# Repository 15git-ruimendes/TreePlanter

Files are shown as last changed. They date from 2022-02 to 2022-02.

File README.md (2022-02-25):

# TreePlanter (RePlantProject)

This project was developed under the guidance and tutelage of professor Armando Sousa and engineer Rui Coutinho has a semester project applied in the curricular unit of engineering systems at the faculty of engeneering at univerisity of Porto.

The final objective of this project is the creation of a smart autonomous planting machine capable of planting a differently sized seedlings amongs harsh and changable terrain.

The scope of the devolpment portion achived throught this semester resulted in the following prototype.

## Directory Organization 

The code gathered in this directory was organized as follows:

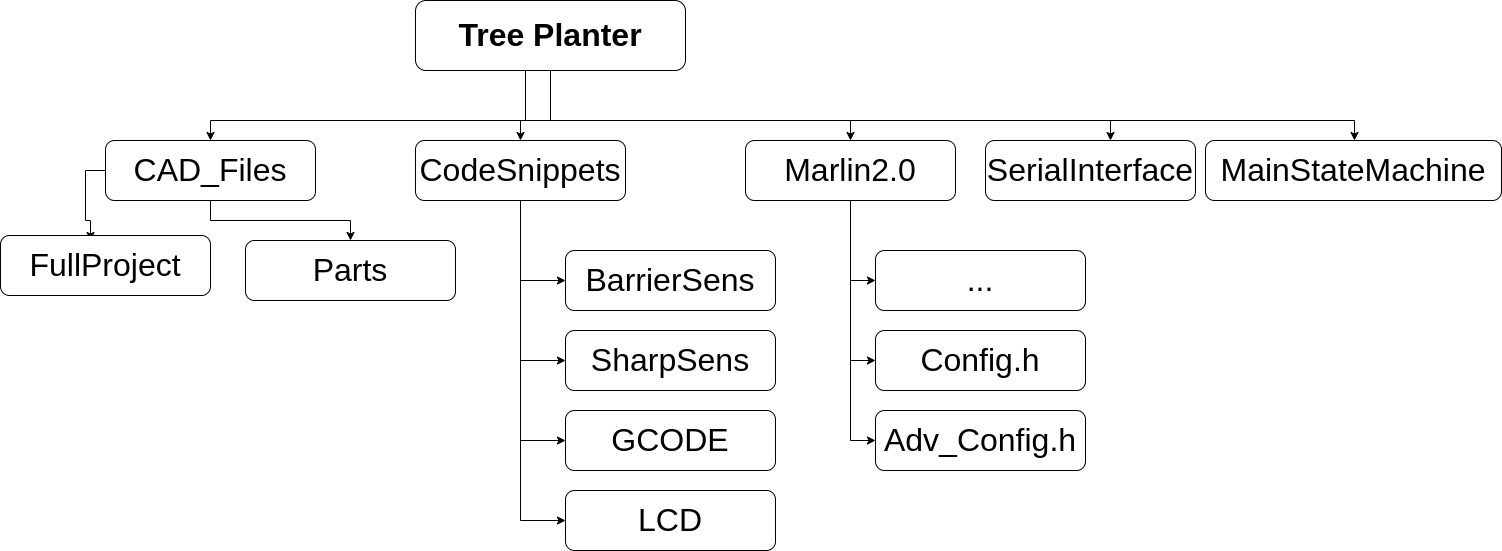
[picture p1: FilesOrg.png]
Files Diagram
  
  
  Thusly, the code present in the Marlin folder discribes the firmware used to control the manipulator that moves the drill. This firmware was corrected and altered for the porpouses of this project and to control and combine with the shield RAMPS 1.4 used.
  
  Next the code sections presented in MainStateMachine gather the hardware test code for the different sensores used and a liberarly for the LCD display. This folder also includes the main code used to control this project.
  The folder named SerialInterface presents the code used to create the serial interface, this code was developed using PySide2 and QtCreator.
  
  ## Connections Diagram
  
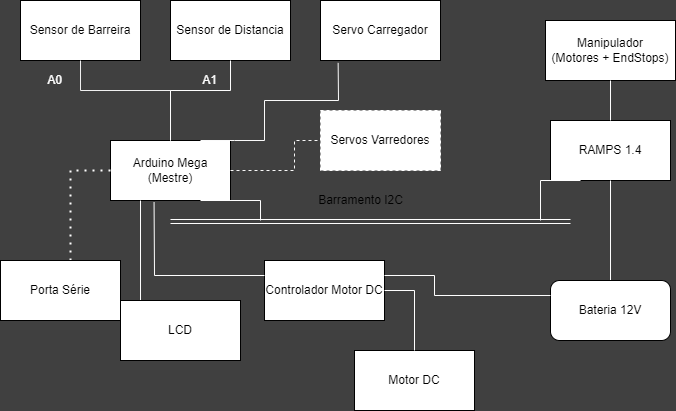
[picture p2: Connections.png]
Connection Diagram
  
  
  ## State Machine Diagram
  
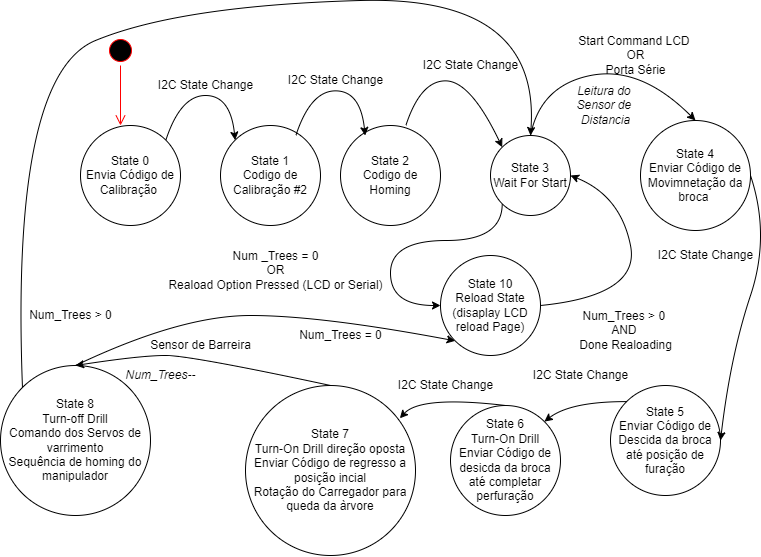
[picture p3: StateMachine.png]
State Machine Diagram


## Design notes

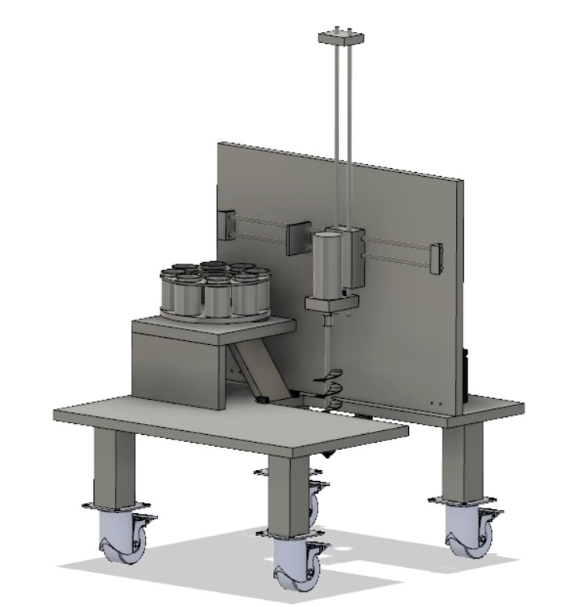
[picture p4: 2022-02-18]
GUI_TreePlanter/Pos2.jpg

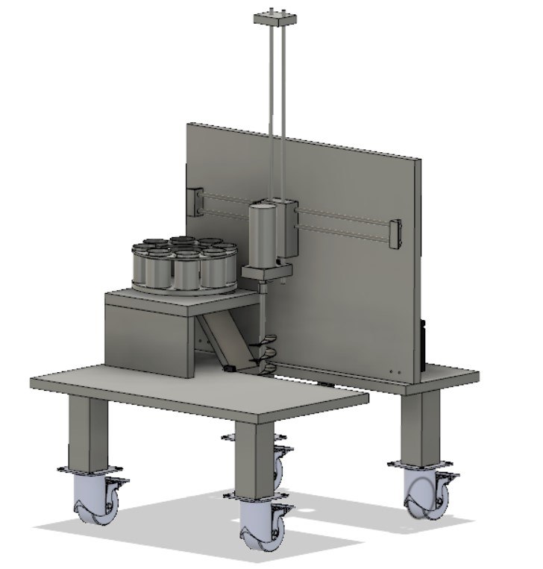
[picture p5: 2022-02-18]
GUI_TreePlanter/Pos1.jpg

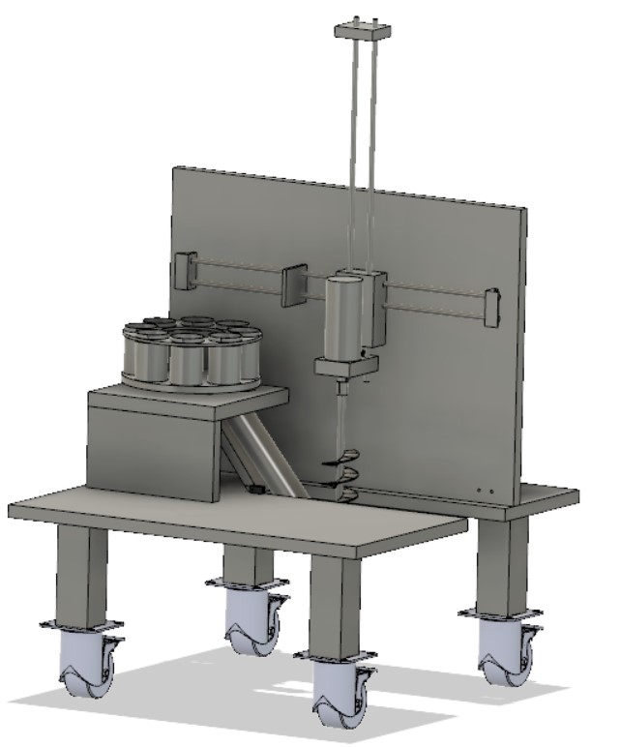
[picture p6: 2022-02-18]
GUI_TreePlanter/Pos4.jpg

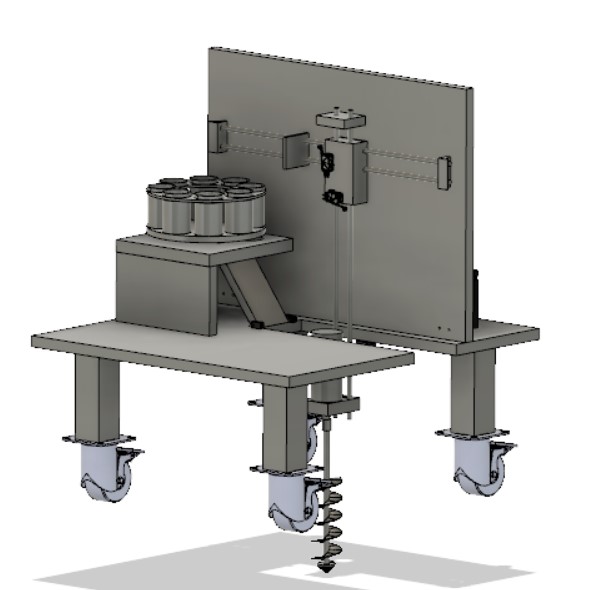
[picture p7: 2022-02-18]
GUI_TreePlanter/Pos3.jpg

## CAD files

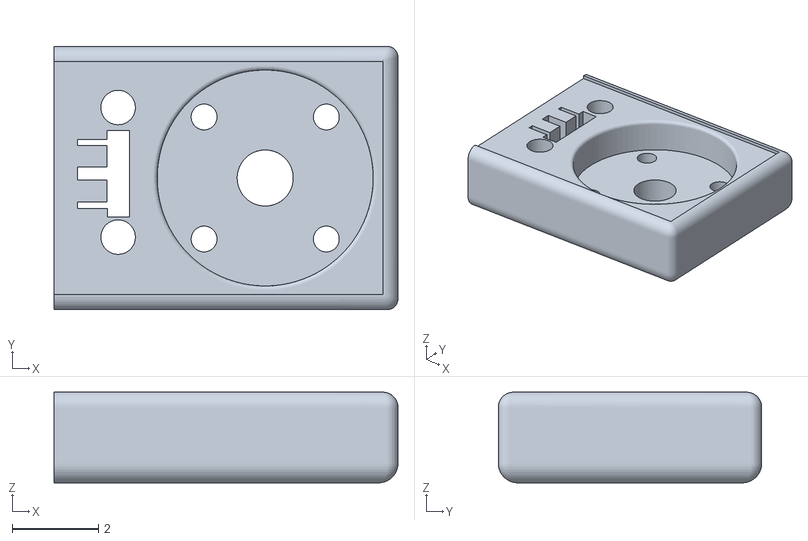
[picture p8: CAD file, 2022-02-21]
CAD_Files/IndividualParts/DC_Mount.stl
7.97 x 6.10 x 2.10

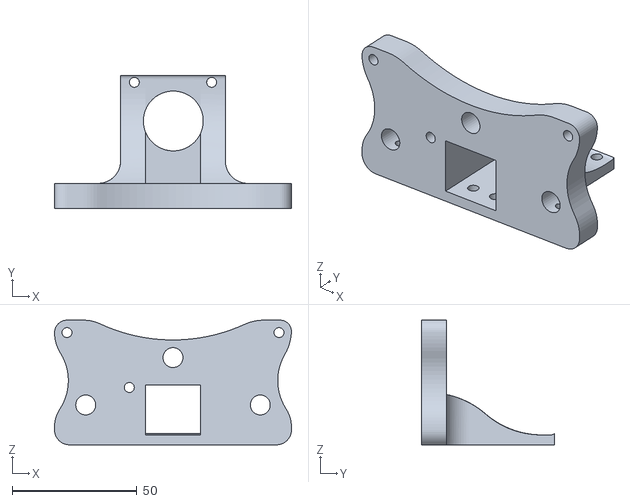
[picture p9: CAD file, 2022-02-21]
CAD_Files/IndividualParts/ManipulatorMountSimpler.stl
95.0 x 53.2 x 50.0

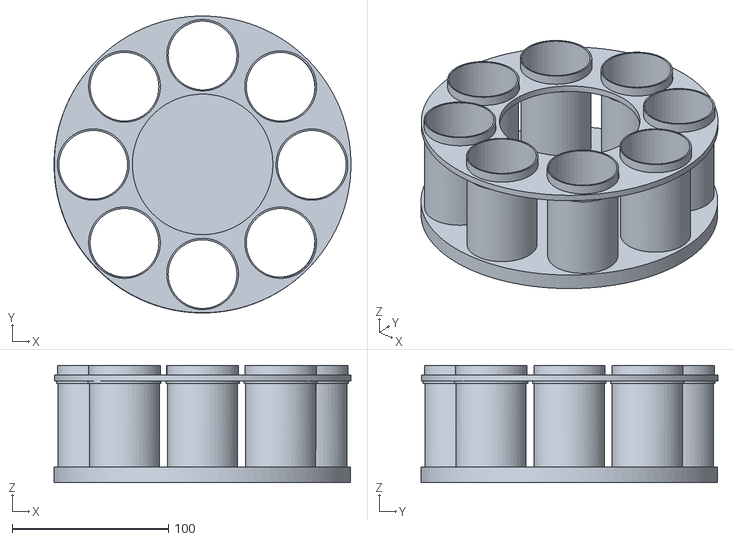
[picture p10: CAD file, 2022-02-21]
CAD_Files/IndividualParts/Carregador.stl
190.1 x 190.2 x 75.0

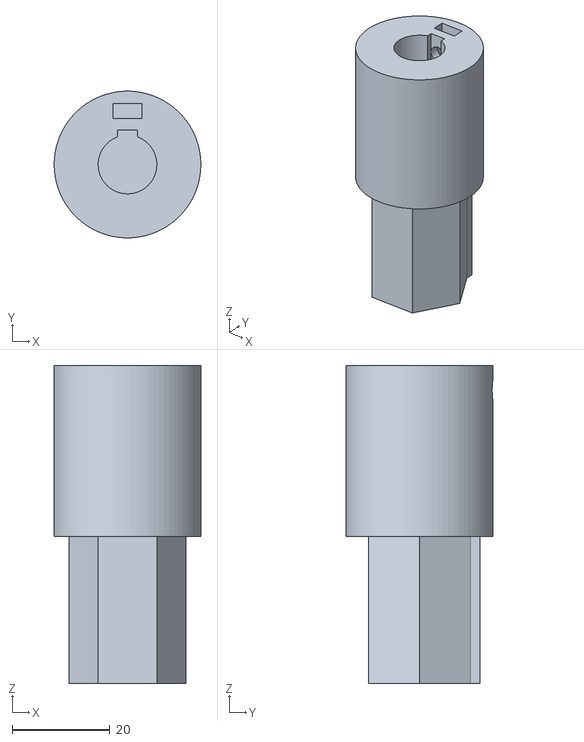
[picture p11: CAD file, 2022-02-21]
CAD_Files/IndividualParts/Coupler.stl
30.0 x 30.0 x 65.0

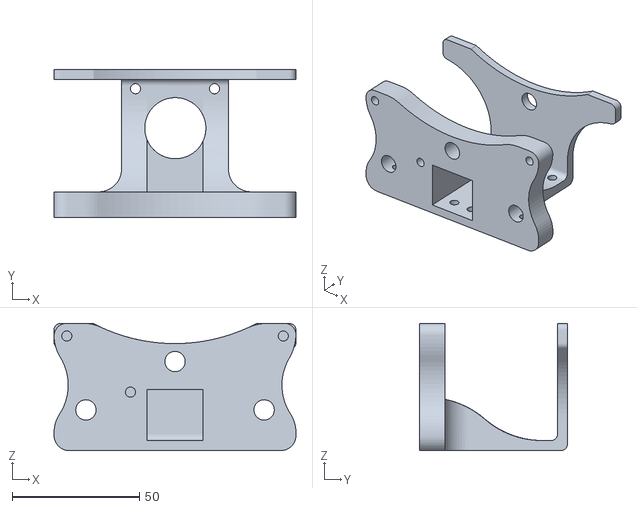
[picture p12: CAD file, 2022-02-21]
CAD_Files/IndividualParts/ManipulatorMount.stl
95.0 x 58.0 x 50.0

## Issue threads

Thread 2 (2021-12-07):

I2C communication Slave-Master

AlexMiranda16, 2021-12-07:
Slave can send data to the master

AlexMiranda16, 2021-12-08:
Since the master is the one that request a response from the slave, the slave says if it's free or not.
A weird bug makes some times the slave locked in a G-code command. Might be a g-code/Marlin problem.
A fix is to make the slave a "master" and he will send when it's ready to receive a new command, instead of being asked if it's free or not

AlexMiranda16, 2021-12-18:
I2C communication doesn't seems to be the problem.
The problem might be in the queue.advance that does not "lock" the ramps code, asking right away for a new command to the Arduino.
The queue is full and does not accept more commands, due to a very long time of command execution.
A solution might be using M400 command for ensure that all the moves are finished.

Closed 2021-12-31.

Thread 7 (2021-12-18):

Adjust micro-stepping in Gcode and Ramps

AlexMiranda16, 2021-12-18:
Configuration required to adjust the manipulator (and other subsystem modules eventually)

AlexMiranda16, 2021-12-18:
Steps required to configure the Steps/MM motor movement in Ramps (X, Y, Z):

- In "configuration.h" adjust the step_per_unit values;
- Use a ruler (or other precise way of measure) to measure the current place of the "head"
- Make it move X mm (like 100mm)
- Measure the new location to see how much it really moves
- Make the calculation: (steps_per_unit * Xmm) / actualmovement
- Replace the step_per_unit with the new value
- Repeat previous steps again until obtained reasonable results and to other axis

AlexMiranda16, 2021-12-19:
In this link it has some more formulas:
https://www.matterhackers.com/news/3d-printer-firmware-settings-stepper-motor-configuration
There is another way to calibrate belt driven axis (our case X and Y) but it looks more complicated.

AlexMiranda16, 2022-01-07:
Configured!
There is no micro-stepping applied.
Steps per unit are 5.15 in the manipulator (a variation of about 1mm in every 100mm)

Closed 2022-01-07.

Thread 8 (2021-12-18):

Configure endstops

AlexMiranda16, 2021-12-18:
It's required to activate the pull-up resistor.
Add the mechanical endstop.
Configure software endstop.

AlexMiranda16, 2021-12-18:
Marlin Configuration for the EndStops using a Pull-up Resistor:

- Go to "Configuration.h"
- Check if "#define ENDSTOPPULLUPS" is uncommented
- Go to "// Mechanical endstop with COM to ground and NC..." and change the value

AlexMiranda16, 2021-12-19:
The EndStops are working properly.
Its is required to check how to make them stop the motors in case of an activation.
It is also required to calibrate the software EndStops.

AlexMiranda16, 2021-12-21:
For Software endstops:

- Go to Configuration.h
- Search for "X_MAX_POS" and change the value to the max position of the required axis (x and y)

AlexMiranda16, 2021-12-29:
Possible reasons why endstops are not working properly:
- It is required to set the machine to the homing position, using the "G28" command. In this case use "G28 X Y"
- In configuration.adv check "//#define ENDSTOPS_ALWAYS_ON_DEFAULT" (maybe should be uncommented)
- From a read forum [1] if only X and Y axis are homed, soft and hardware endstops are ignored. (Home all axis and say that Z is always homed)
- In configuration check "//#define NO_MOTION_BEFORE_HOMING" (maybe should be commented)

Other things to have attention:
- Command "M120" -> Enables EndStops
- Command "M119" -> Read the EndStops States
- Command "M211" -> Software EndStops (Enable/Disable)

[1] https://github.com/MarlinFirmware/Marlin/issues/16373

AlexMiranda16, 2021-12-31:
EndStops are working.
Besides the configuration, the Z axis endstop is set as always trigered so that G28 command works activating all endstops.

There is a problem thought.
After some seconds, if all axis are not homed, an error will occur : "Error: Printer halted. kill() called!".
A solution might be tricking the machine thinking that it is at an positive position (because when initialized the position is 0). That way, it will think that it is actually required to travel some distance and might not return the error.
Use a initial position as big as at least the size of the manipulator space, in case this solution actually works.

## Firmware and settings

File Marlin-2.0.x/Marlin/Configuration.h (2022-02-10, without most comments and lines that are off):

#pragma once
#define CONFIGURATION_H_VERSION 02000902
#define STRING_CONFIG_H_AUTHOR "(none, default config)" // Who made the changes.
#define SHOW_BOOTSCREEN
#define SERIAL_PORT 0
#define BAUDRATE 115200
#define BAUD_RATE_GCODE     // Enable G-code M575 to set the baud rate
#define MOTHERBOARD BOARD_RAMPS_14_EFB
#if LINEAR_AXES >= 4
#define AXIS4_NAME 'A' // :['A', 'B', 'C', 'U', 'V', 'W']
#endif
#if LINEAR_AXES >= 5
#define AXIS5_NAME 'B' // :['A', 'B', 'C', 'U', 'V', 'W']
#endif
#if LINEAR_AXES >= 6
#define AXIS6_NAME 'C' // :['A', 'B', 'C', 'U', 'V', 'W']
#endif
#define EXTRUDERS 1
#define DEFAULT_NOMINAL_FILAMENT_DIA 1.75
#define TEMP_SENSOR_0 1
#define TEMP_SENSOR_1 0
#define TEMP_SENSOR_2 0
#define TEMP_SENSOR_3 0
#define TEMP_SENSOR_4 0
#define TEMP_SENSOR_5 0
#define TEMP_SENSOR_6 0
#define TEMP_SENSOR_7 0
#define TEMP_SENSOR_BED 0
#define TEMP_SENSOR_PROBE 0
#define TEMP_SENSOR_CHAMBER 0
#define TEMP_SENSOR_COOLER 0
#define TEMP_SENSOR_BOARD 0
#define TEMP_SENSOR_REDUNDANT 0
#define DUMMY_THERMISTOR_998_VALUE 25
#define DUMMY_THERMISTOR_999_VALUE 100
#define TEMP_RESIDENCY_TIME 10 // (seconds) Time to wait for hotend to "settle" in M109
#define TEMP_WINDOW 1          // (°C) Temperature proximity for the "temperature reached" timer
#define TEMP_HYSTERESIS 3      // (°C) Temperature proximity considered "close enough" to the target
#define TEMP_BED_RESIDENCY_TIME 10 // (seconds) Time to wait for bed to "settle" in M190
#define TEMP_BED_WINDOW 1          // (°C) Temperature proximity for the "temperature reached" timer
#define TEMP_BED_HYSTERESIS 3      // (°C) Temperature proximity considered "close enough" to the target
#define TEMP_CHAMBER_RESIDENCY_TIME 10 // (seconds) Time to wait for chamber to "settle" in M191
#define TEMP_CHAMBER_WINDOW 1          // (°C) Temperature proximity for the "temperature reached" timer
#define TEMP_CHAMBER_HYSTERESIS 3      // (°C) Temperature proximity considered "close enough" to the target
#if TEMP_SENSOR_REDUNDANT
#define TEMP_SENSOR_REDUNDANT_SOURCE E1   // The sensor that will provide the redundant reading.
#define TEMP_SENSOR_REDUNDANT_TARGET E0   // The sensor that we are providing a redundant reading for.
#define TEMP_SENSOR_REDUNDANT_MAX_DIFF 10 // (°C) Temperature difference that will trigger a print abort.
#endif
#define HEATER_0_MINTEMP 5
#define HEATER_1_MINTEMP 5
#define HEATER_2_MINTEMP 5
#define HEATER_3_MINTEMP 5
#define HEATER_4_MINTEMP 5
#define HEATER_5_MINTEMP 5
#define HEATER_6_MINTEMP 5
#define HEATER_7_MINTEMP 5
#define BED_MINTEMP 5
#define CHAMBER_MINTEMP 5
#define HEATER_0_MAXTEMP 275
#define HEATER_1_MAXTEMP 275
#define HEATER_2_MAXTEMP 275
#define HEATER_3_MAXTEMP 275
#define HEATER_4_MAXTEMP 275
#define HEATER_5_MAXTEMP 275
#define HEATER_6_MAXTEMP 275
#define HEATER_7_MAXTEMP 275
#define BED_MAXTEMP 150
#define CHAMBER_MAXTEMP 60
#define HOTEND_OVERSHOOT 15 // (°C) Forbid temperatures over MAXTEMP - OVERSHOOT
#define BED_OVERSHOOT 10    // (°C) Forbid temperatures over MAXTEMP - OVERSHOOT
#define COOLER_OVERSHOOT 2  // (°C) Forbid temperatures closer than OVERSHOOT
#define PIDTEMP
#define BANG_MAX 255     // Limits current to nozzle while in bang-bang mode; 255=full current
#define PID_MAX BANG_MAX // Limits current to nozzle while PID is active (see PID_FUNCTIONAL_RANGE below); 255=full current
#define PID_K1 0.95      // Smoothing factor within any PID loop
#define DEFAULT_Kp 22.20
#define DEFAULT_Ki 1.08
#define DEFAULT_Kd 114.00
#define MAX_BED_POWER 255 // limits duty cycle to bed; 255=full current
#define MAX_CHAMBER_POWER 255 // limits duty cycle to chamber heater; 255=full current
#define PID_FUNCTIONAL_RANGE 10 // If the temperature difference between the target temperature and the actual temperature \
#define PREVENT_COLD_EXTRUSION
#define EXTRUDE_MINTEMP 170
#define PREVENT_LENGTHY_EXTRUDE
#define EXTRUDE_MAXLENGTH 200
#define THERMAL_PROTECTION_HOTENDS // Enable thermal protection for all extruders
#define THERMAL_PROTECTION_BED     // Enable thermal protection for the heated bed
#define THERMAL_PROTECTION_CHAMBER // Enable thermal protection for the heated chamber
#define THERMAL_PROTECTION_COOLER  // Enable thermal protection for the laser cooling
#define COREXY
#define USE_XMIN_PLUG
#define USE_YMIN_PLUG
#define USE_ZMIN_PLUG
#define ENDSTOPPULLUPS
#define X_MIN_ENDSTOP_INVERTING false       // Set to true to invert the logic of the endstop.
#define Y_MIN_ENDSTOP_INVERTING false       // Set to true to invert the logic of the endstop.
#define Z_MIN_ENDSTOP_INVERTING false       // Set to true to invert the logic of the endstop.
#define I_MIN_ENDSTOP_INVERTING false       // Set to true to invert the logic of the endstop.
#define J_MIN_ENDSTOP_INVERTING false       // Set to true to invert the logic of the endstop.
#define K_MIN_ENDSTOP_INVERTING false       // Set to true to invert the logic of the endstop.
#define X_MAX_ENDSTOP_INVERTING false       // Set to true to invert the logic of the endstop.
#define Y_MAX_ENDSTOP_INVERTING false       // Set to true to invert the logic of the endstop.
#define Z_MAX_ENDSTOP_INVERTING false       // Set to true to invert the logic of the endstop.
#define I_MAX_ENDSTOP_INVERTING false       // Set to true to invert the logic of the endstop.
#define J_MAX_ENDSTOP_INVERTING false       // Set to true to invert the logic of the endstop.
#define K_MAX_ENDSTOP_INVERTING false       // Set to true to invert the logic of the endstop.
#define Z_MIN_PROBE_ENDSTOP_INVERTING false // Set to true to invert the logic of the probe.
#define X_DRIVER_TYPE A4988
#define Y_DRIVER_TYPE A4988
#define Z_DRIVER_TYPE A4988
#define E0_DRIVER_TYPE A4988
#define E1_DRIVER_TYPE A4988
#define DEFAULT_AXIS_STEPS_PER_UNIT \
  {                                 \
    5.15, 5.15, 400, 500                \
  }
#define DEFAULT_MAX_FEEDRATE \
  {                          \
    300, 300, 5, 25          \
  }
#define DEFAULT_MAX_ACCELERATION \
  {                              \
    3000, 3000, 100, 10000       \
  }
#define DEFAULT_ACCELERATION 3000         // X, Y, Z and E acceleration for printing moves
#define DEFAULT_RETRACT_ACCELERATION 3000 // E acceleration for retracts
#define DEFAULT_TRAVEL_ACCELERATION 3000  // X, Y, Z acceleration for travel (non printing) moves
#define DEFAULT_EJERK 5.0 // May be used by Linear Advance
#define JUNCTION_DEVIATION_MM 0.013 // (mm) Distance from real junction edge
#define JD_HANDLE_SMALL_SEGMENTS    // Use curvature estimation instead of just the junction angle \
#define Z_MIN_PROBE_USES_Z_MIN_ENDSTOP_PIN
#define NOZZLE_TO_PROBE_OFFSET \
  {                            \
    10, 10, 0                  \
  }
#define PROBING_MARGIN 10
#define XY_PROBE_FEEDRATE (133 * 60)
#define Z_PROBE_FEEDRATE_FAST (4 * 60)
#define Z_PROBE_FEEDRATE_SLOW (Z_PROBE_FEEDRATE_FAST / 2)
#define Z_CLEARANCE_DEPLOY_PROBE 10  // Z Clearance for Deploy/Stow
#define Z_CLEARANCE_BETWEEN_PROBES 5 // Z Clearance between probe points
#define Z_CLEARANCE_MULTI_PROBE 5    // Z Clearance between multiple probes
#define Z_PROBE_LOW_POINT -2 // Farthest distance below the trigger-point to go before stopping
#define Z_PROBE_OFFSET_RANGE_MIN -20
#define Z_PROBE_OFFSET_RANGE_MAX 20
#define X_ENABLE_ON 0
#define Y_ENABLE_ON 0
#define Z_ENABLE_ON 0
#define E_ENABLE_ON 0 // For all extruders
#define DISABLE_X false
#define DISABLE_Y false
#define DISABLE_Z false
#define DISABLE_E false           // Disable the extruder when not stepping
#define DISABLE_INACTIVE_EXTRUDER // Keep only the active extruder enabled
#define INVERT_X_DIR false
#define INVERT_Y_DIR true
#define INVERT_Z_DIR false
#define INVERT_E0_DIR false
#define INVERT_E1_DIR false
#define INVERT_E2_DIR false
#define INVERT_E3_DIR false
#define INVERT_E4_DIR false
#define INVERT_E5_DIR false
#define INVERT_E6_DIR false
#define INVERT_E7_DIR false
#define X_HOME_DIR -1
#define Y_HOME_DIR -1
#define Z_HOME_DIR -1
#define X_BED_SIZE 350//200
#define Y_BED_SIZE 350//200
#define X_MIN_POS 0
#define Y_MIN_POS 0
#define Z_MIN_POS 0
#define X_MAX_POS X_BED_SIZE
#define Y_MAX_POS Y_BED_SIZE
#define Z_MAX_POS 200
#define MIN_SOFTWARE_ENDSTOPS
#define MIN_SOFTWARE_ENDSTOP_X
#define MIN_SOFTWARE_ENDSTOP_Y
#define MIN_SOFTWARE_ENDSTOP_Z
#define MIN_SOFTWARE_ENDSTOP_I
#define MIN_SOFTWARE_ENDSTOP_J
#define MIN_SOFTWARE_ENDSTOP_K
#define MAX_SOFTWARE_ENDSTOPS
#define MAX_SOFTWARE_ENDSTOP_X
#define MAX_SOFTWARE_ENDSTOP_Y
#define MAX_SOFTWARE_ENDSTOP_Z
#define MAX_SOFTWARE_ENDSTOP_I
#define MAX_SOFTWARE_ENDSTOP_J
#define MAX_SOFTWARE_ENDSTOP_K
#define HOMING_FEEDRATE_MM_M       \
  {                                \
    (50 * 60), (50 * 60), (4 * 60) \
  }
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

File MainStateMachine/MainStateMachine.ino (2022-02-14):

#include <TB9051FTGMotorCarrier.h>

#include "Servo.h"
#include "Arduino.h"
#include "LCD_display.h"
#include "Gcode.h"
#include "U8glib.h"
#include <SharpIR.h>

#define TREE_LIMIT 6
#define TREE_DELAY 1000
#define DELAY 250

#define BUZZERPIN 7

#define DIST_SENS A1
#define DIST_SENS_MODEL 1080
#define BARRIER 19

#define ENC_BUTTON 18
#define ENC_RIGHT 2
#define ENC_LEFT 3

#define DRILL_EN 10
#define DRILL_PWM1 5
#define DRILL_PWM2 6
#define DRILL_MOTOR 5

#define UP 0
#define DOWN 180
#define TIMER_MS 1500

#define ServoPin 9

SharpIR detect(SharpIR::GP2Y0A41SK0F, A1);


//Servo
Servo sweeper_left, sweeper_right;
int pin_left = 11, pin_right = 12;
int servo_state = 0, rotator_state = 0;
unsigned long timer_1 = 0;
unsigned long timer_2 = 0;

int trees = 0, pos = 0;
bool treeDropped = false;
float distance = 0;
int page = 1;
int movement, manipulator_state = 0, state = 0, res, top_page = 0, reload = 0, prev_state = 1;
static unsigned long last_interrupt = 0, prev_time = 0, treeWait = 0;

float speed = 0;
static TB9051FTGMotorCarrier driver{DRILL_PWM1, DRILL_PWM2};
U8GLIB_ST7920_128X64_1X u8g(23, 17, 16);
display lcd;
Servo treeDrop;
void setup()
{
    treeDrop.attach(ServoPin);
    driver.enable();
    gcode_configuration();
    lcd.setup_LCD(u8g);
    Serial.begin(115200);

    pinMode(ENC_BUTTON, INPUT_PULLUP);
    attachInterrupt(digitalPinToInterrupt(ENC_BUTTON), click, FALLING);
    pinMode(ENC_RIGHT, INPUT_PULLUP);
    attachInterrupt(digitalPinToInterrupt(ENC_RIGHT), right, FALLING);
    pinMode(ENC_LEFT, INPUT_PULLUP);
    attachInterrupt(digitalPinToInterrupt(ENC_LEFT), left, FALLING);

    pinMode(BARRIER,INPUT_PULLUP);
    attachInterrupt(digitalPinToInterrupt(BARRIER),read_Barrier_Sens,LOW);
    //attachInterrupt(digitalPinToInterrupt(BARRIER),read_Barrier_Sens,
    // while (!calibrate_Manipulator());

    //Servo
    sweeper_left.attach(pin_left);
    sweeper_right.attach(pin_right);
}

void start_timer(unsigned long &timer){
    timer = millis();
}

bool check_timer(unsigned long timer, unsigned long interval){
  return ((millis()-timer) >= interval);
}

void sweeper_sweep(){
  sweeper_left.write(UP);
  sweeper_right.write(DOWN);
}

void sweeper_home(){
  sweeper_left.write(DOWN);
  sweeper_right.write(UP);
}

float read_Distance()
{
    return detect.getDistance();
}

void turn_Drill(int on)
{
    /*if (on)
    {
        for (int i = 0; i < 10; i++)
        {
            driver.setOutput(speed);
            speed += 0.1;
            delay(100);
        }
    }
    if (on == -1)
    {
        for (int i = 0; i < 10; i++)
        {
            driver.setOutput(speed);
            speed -= 0.1;
            delay(100);
        }

        // Ramp up to full reverse throttle
        for (int i = 0; i < 5; i++)
        {
            driver.setOutput(speed);
            speed -= 0.1;
            delay(100);
        }
    }
    if (on == 0)
    {
        if (speed < 0)
        {
            for (auto i{0}; i < 10; i++)
            {
                if (speed == 0)
                    break;
                driver.setOutput(speed);
                speed += 0.1;
                delay(100);
            }
            speed = 0;
            driver.setOutput(speed);
        }
        else
        {
            for (int i = 0; i < 10; i++)
            {
                if (speed == 0)
                    break;
                driver.setOutput(speed);
                speed -= 0.1;
                delay(100);
            }
            speed = 0;
            driver.setOutput(speed);
        }
    }*/

    if (on) 
      digitalWrite(DRILL_MOTOR,HIGH);
    else 
      digitalWrite(DRILL_MOTOR,LOW);
}

bool read_Barrier_Sens()
{
  /*if(millis() - last_interrupt < DELAY || treeDropped == true){
    return;
  }*/
  if (state == 7 && rotator_state == 0)
  {
    treeDropped = true;
    //Serial.println("caiou Crl");
  }
    
  else 
    treeDropped = false;
  
    
}

void click()
{
    if (millis() - last_interrupt < DELAY) // Debounce
    {
        last_interrupt = millis();
        return;
    }
    last_interrupt = millis();
    Serial.println("button");
    if (state != 3 && state != 10){
      //state = 401;
    }
        //state = 401;
    else if (state == 3 && top_page)
    {
        state = 10; // Reload page
    }
    else if (state == 10 && (trees > 0))
    {
        state = 3;
        top_page = 0;
    }
    else if (state == 3 && top_page == 0)
        state = 4;
}
void right()
{
    if (millis() - last_interrupt < DELAY) // Debounce
    {
        last_interrupt = millis();
        return;
    }
    last_interrupt = millis();
    Serial.println("right");
    if (page != 0)
        top_page = 1;
    else if (page == 0)
        trees += (trees < TREE_LIMIT);
}
void left()
{
    if (millis() - last_interrupt < DELAY) // Debounce
    {
        last_interrupt = millis();
        return;
    }
    last_interrupt = millis();
    Serial.println("left");
    if (page != 0)
        top_page = 0;
    else if (page == 0)
        trees -= (trees > 0);
}

void loop()
{

    
    //treeDropped = read_Barrier_Sens();
    // LCD functions
    u8g.firstPage();
    do
    {
        lcd.display_LCD(page, u8g, top_page, trees);
    } while (u8g.nextPage());

    // Serial Communications Functions
    if (prev_state != state)
    {
        prev_state = state;
        if (state < 10)
        {
            Serial.print("St: 00");
            Serial.println(state);
        }
        else if (state < 100)
        {
            Serial.print("St: 0");
            Serial.println(state);
        }
        else
        {
            Serial.print("St: ");
            Serial.println(state);
        }
        Serial.print("Tr: 00");
        Serial.println(trees);
    }
    while (Serial.available() > 0)
    {
        char res = (char)Serial.read();
        Serial.print(res);
        if (state == 3 && res == 'R')
            state = 10;
        if ((state == 3 || state == 10) && trees > 0 && res == 'B')
            state = 4;
        if (state != 3 && res == 'S')
            state = 401;
        else if (state == 3 || state == 10)
        {
            trees = (int)res - 48;
            Serial.println(trees);
        }
    }
    // States to Stop Manipulator Movement
    if (state < 3 && manipulator_state < 3)
    {
        manipulator_control(manipulator_state, int(distance));
        state = manipulator_state;
    }
    if (state >= 4 && state != 7&& state != 10 && state != 401)
    {
        manipulator_control(manipulator_state, int(distance));
        switch (manipulator_state)
        {
        case 3:
            state = 4;
            break;
        case 4:
            state = 4;
            break;
        case 5:
            state = 4;
            break;
        case 6:
            state = 5;
            break;
        case 8:
            state = 7;
            break;
        default:
            break;
        }
    }
    // Recicle State
    if (state == 8 && manipulator_control(manipulator_state, int(distance)) == DONE)
    {
        manipulator_state = 3;
        state = 3;
    }

    // Error State
    if (state == 401){
      // infinite tree not found
      manipulator_state = 401;
      page = 101;
    }
        

    // Retry to deploy a tree from the magazine if tree is not detected within TREE_DELAY ms
    if (state == 7 && (millis() - treeWait > TREE_DELAY))
    {
      //Starts the rotator machine state
      
      rotator_state = 1;
        
      treeWait = millis();
    }

    // Reload State
    if (state == 3 && trees == 0){
        state = 10;
        distance = read_Distance()*20;
        if (distance > 120){
          distance = 12;
        }
        //Serial.println((int)distance);
    }
    // Testing
    /*if (state >= 0 && state <= 6)
    {
        delay(1000);
        state++;
    }*/

    switch (state)
    {
    case 0: // Calibrate
        page = 100;
        break;
    case 1: // Calibrate
        page = 100;
        break;
    case 2: // Calibrate
        page = 100;
        break;
    case 3: // Waiting for start
        page = 1;
        distance = read_Distance()*20;
        if (distance > 120){
          distance = 12;
        }
        //Serial.println((int)distance);
        break;
    case 4: // Moving drill
        page = 2;
        break;
    case 5: // Drilling
        turn_Drill(1);
        page = 3;
        break;
    case 6: // Moving Drill
        page = 2;
        treeDropped = false;
        break;
    case 7: // Drop tree
        turn_Drill(0);
        if (treeDropped)
        {
            trees--;
            state++;
            // Stop Servo
            // Continue Machine State
            // Comment this line when sweepers are built and
            // system to drop dirt is built
            manipulator_state = 8;
            servo_state = 1;
        }
        page = 4;
        break;
    case 8: // Sweepers (not built)
        page = 5;
        treeDropped = false;
        
        break;
    case 10: // Reload
        page = 0;
        break;
    default:
        break;
    }

    //Servo state machine
    switch(servo_state){
      
    case 0:
      //Check if this line is not fucking everything up
        
      break;
    case 1:
        start_timer(timer_1);
       
        sweeper_sweep();
        servo_state = 2;
        
        //Serial.println("Sweeping");
      break;
    case 2:
      if(check_timer(timer_1,TIMER_MS)){

        sweeper_home();
        servo_state = 0;
        //Serial.println("Returning home");
      }
      break;
  }

  //Rotator state
  switch(rotator_state){
      case 0:
        break;
      case 1:
        treeDrop.write(45);
        start_timer(timer_2);
        rotator_state = 2;
        break;
      case 2:
        if(check_timer(timer_2,124)){
          
          treeDrop.write(90);
          rotator_state = 0;
          //Serial.println("Rota");
        }
        break;
    }


    
}

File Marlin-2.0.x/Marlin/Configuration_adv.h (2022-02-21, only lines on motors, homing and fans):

#define E0_AUTO_FAN_PIN -1
#define E1_AUTO_FAN_PIN -1
#define E2_AUTO_FAN_PIN -1
#define E3_AUTO_FAN_PIN -1
#define E4_AUTO_FAN_PIN -1
#define E5_AUTO_FAN_PIN -1
#define E6_AUTO_FAN_PIN -1
#define E7_AUTO_FAN_PIN -1
#define CHAMBER_AUTO_FAN_PIN -1
#define COOLER_AUTO_FAN_PIN -1
#define COOLER_FAN_PIN -1
#define HOMING_BUMP_MM \
#define HOMING_BUMP_DIVISOR \
#define HOME_Y_BEFORE_X // If G28 contains XY home Y before X
#define MICROSTEP_MODES    \

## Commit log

2021-11-29 Marlin Copy
    [Configuration.h, Configuration_adv.h, esp32.csv]
2021-12-03 Added I2C receiver in Marlin
    Created receiver in MarlinCore.cpp
    [Configuration.h, Configuration_adv.h]
2021-12-03 Add i2c master and change conf
    [Configuration.h, Configuration_adv.h]
2021-12-07 Add gcode state and send/request to marlin
2021-12-08 I2C communication
    Added Ramps onrequest function. Has the function to send to the master to say if it's free or not
    [Configuration_adv.h]
2021-12-17 Added I2C alternative (NOT TESTED)
    Added a small function in Marlin to be able to send a message to the arduino.
    Here, Ramps is considered to be a Master and the Arduino a Slave
2021-12-20 Changes to find microstepping correct values
    [Configuration.h, Configuration_adv.h]
2021-12-21 Test done with esp32 as master arduino mega slave
2021-12-24 Gcode/I2C reorganize
    In Marlin:
    - Reverted to only a slave (now master asks if the ramps is free or not)
    In Arduino:
    - Created functions to configure (use in setup function)
    - Reorganize sendGcode and UpdateState (I2C communication)
    - Created manipulator function, to call in main, when we want to control the manipulator
    [Configuration.h]
2021-12-30 Fix merge conflicts
    [Configuration.h, Configuration_adv.h]
2021-12-30 Working software endstops
    [Configuration.h]
2021-12-30 Tested mechanical endstops
    - The mechanical endstops must be both pressed after G28 is executed,
    otherwise the process will halt.
    - After this phase the program wil run normally.
    - Only one movement is tested.
    - Running the M400 after each command ensures that RAMPS is occupied until
    the movement is completed
2022-01-04 LCD and encoder working missing pages and some parameterization
    [Gcode.cpp, Gcode.h, MainStateMachine.ino]
2022-01-04 LCD exploration and reload pages are working switch case for manipulator added and drill motor control added
2022-01-07 Added emergency and calibration pages to LCD in LCD_display.h and cpp
2022-01-07 Done: calibration and simple state machine
    [Configuration.h]
2022-01-19 with servo motor added
2022-01-22 Implementation of libraries ready to be used in main
    Renamed gcode.ino to gcode_tester.ino, since it is used only for testing the Gcode library created
    Created Gcode.cpp and .h to store the Gcode and i2c communication (for RAMPS)
2022-01-25 Changes and implementation with gcode lib (missing testing)
    [Gcode.cpp, Gcode.h, MainStateMachine.ino]
2022-01-26 Final working model withour dc driver and sweeper
2022-02-03 Emergency stop defined
    [Configuration_adv.h]
2022-02-03 Emergency stop and servo
2022-02-21 Organizing Files
    [Carregador.stl, Coupler.stl, DC_Mount.stl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]

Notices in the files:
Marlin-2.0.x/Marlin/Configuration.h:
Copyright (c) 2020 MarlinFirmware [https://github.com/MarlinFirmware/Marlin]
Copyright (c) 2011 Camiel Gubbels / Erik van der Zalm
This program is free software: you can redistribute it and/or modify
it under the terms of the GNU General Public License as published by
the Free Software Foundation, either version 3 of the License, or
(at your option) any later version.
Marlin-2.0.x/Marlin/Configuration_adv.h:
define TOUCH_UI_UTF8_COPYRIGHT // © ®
